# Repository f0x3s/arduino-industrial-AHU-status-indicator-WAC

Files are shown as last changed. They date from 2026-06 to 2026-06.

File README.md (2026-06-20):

# Arduino Industrial AHU Status Indicator

This project exists as a part of larger infrasctructure to support the laser cutter & digital fabrication space at the Walker Art Center. The laser cutter is vented using an inline blower fan into our paint booth's air handling system several rooms over. It is important that both the inline fan and the paint booth's air handling unit (AHU) are on during laser operation. 

It is easy to verify the status of the inline blower as it is next to the laser, but with the AHU in a separate location a feedback system is required to monitor that the start signal was successfully recieved and alert if the unit turns off for any reason.

<p align="center">
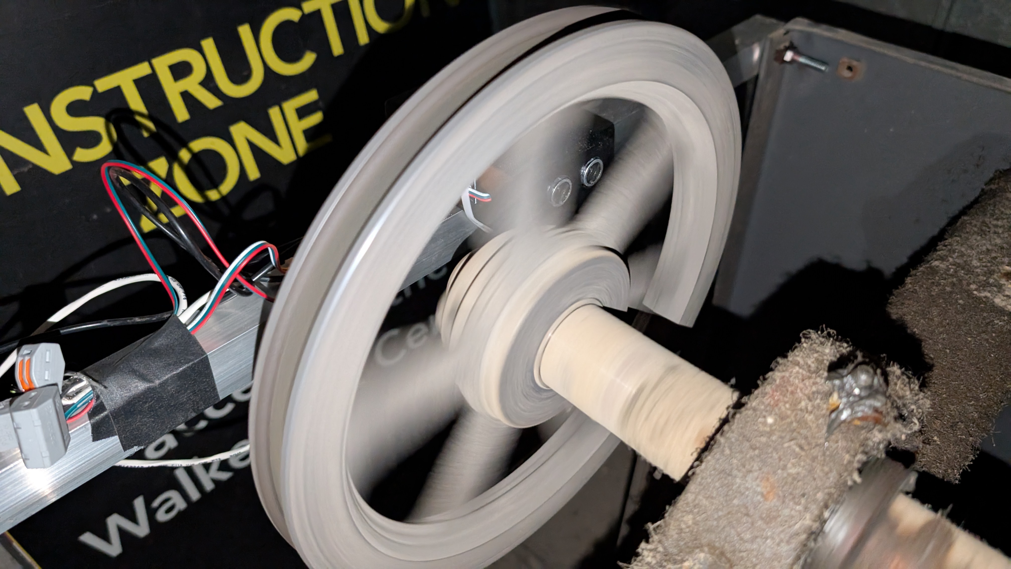
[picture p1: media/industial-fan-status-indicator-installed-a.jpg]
  
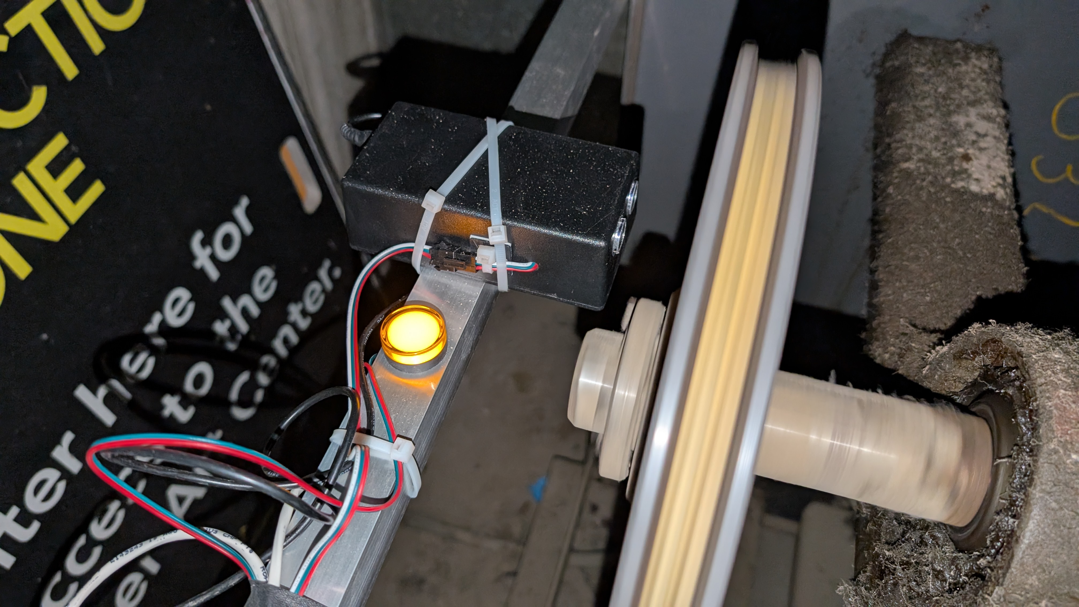
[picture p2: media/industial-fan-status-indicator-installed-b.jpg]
  
</p>

> [Return to: laser-cutter-infrastructure-controls-system-WAC](https://github.com/f0x3s/laser-cutter-infrastructure-controls-system-WAC)
## Behavior

The device uses an ultrasonic sensor to detect passing spokes on the belt and pully system driving the AHU, eliminating any possible ambiguity as to the system's operation. It does this by writing the distance output from the sensor at short intervals into a circular buffer, evaluating for the maximum and minimum distances within the buffer, and triggering a relay if the difference between them exceeds a set threshold. If the fan stops spinning, regardess of whether the pully lands with a spoke or hole in front of the sensor, the buffer will fill up with identical values, and with the threshold no longer met the relay will be deactivated. 

## Required components

* 1x Arduino Uno
* 1x HC-SR04 Ultrasonic Sensor
* 1x 5v Relay Module
* Jumper wire (as needed)
* 2x 24v Indicator lamp
* 1x Project enclosure
* 1x 9v Barrel-jack PSU.
* Wago connectors (as needed)
* Two-conductor stranded wire (as needed)

## Circuit Diagram

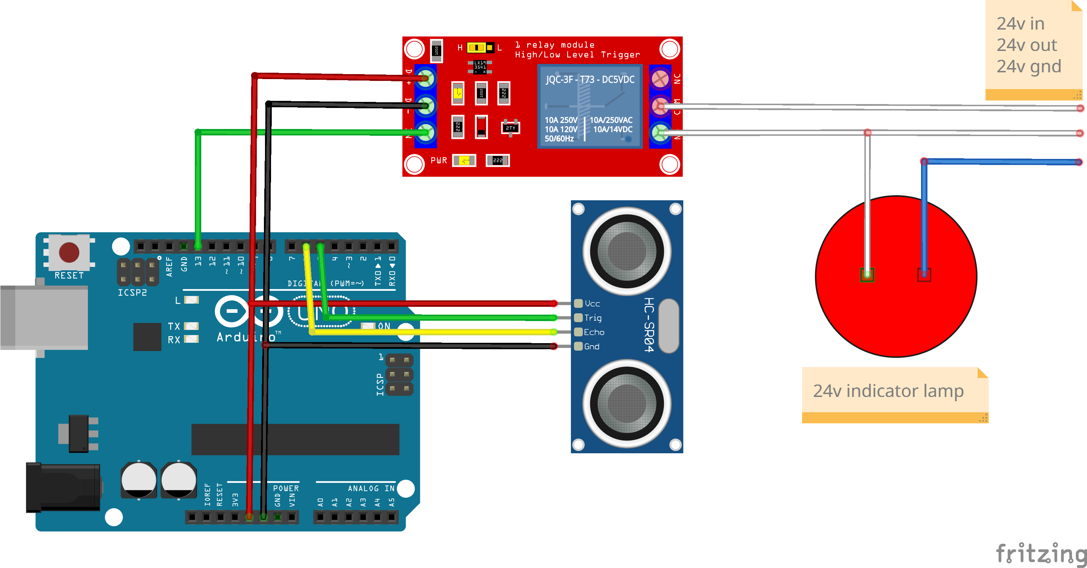
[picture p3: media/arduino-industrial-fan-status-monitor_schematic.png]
electrical schematic


Notes:
* 24v IN to the relay's COM terminal is sourced from the user AHU start signal. This signal remains on for the duration that laser is engaged. This ensures that the feedback lamp will illuminate IFF the fan is spinning && the user has sent a start signal. The lamp will not illuinate if the AHU is activated by someone in the paint booth but an activation request isn't sent from the laser cutter, minimizing confusion.
* Indicator lamp shown on schematic is to placed near the device (see main photos), for local operational verification. The second indicator lamp is placed in room with the laser cutter, receiving the samee 24v signal out from the NO relay terminal and acting as the primary status indiator for the user.
* 24v signals sent over 2-conductor speaker wire or equivalent, all other wires shown are small jumper wires.

## Debugging

sample expected serial output:
<br>
<br>
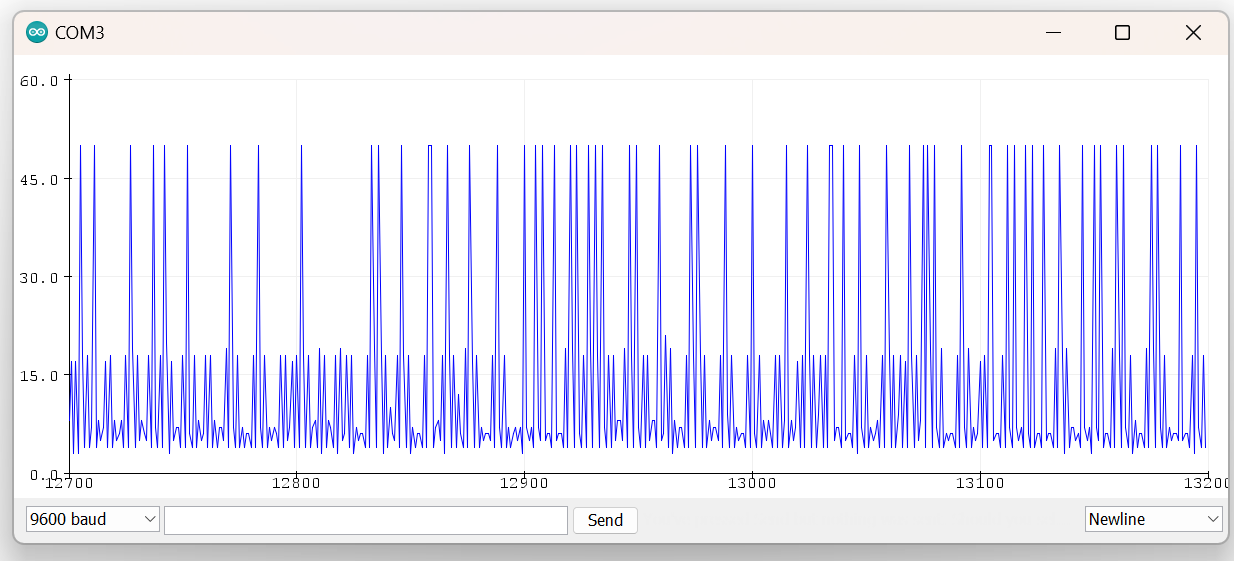
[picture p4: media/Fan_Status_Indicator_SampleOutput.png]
example serial output

<br>
<br>
If the relay is not triggering, the spoke/no spoke distance values may be identified with the serial plotter and the threshold adjusted accordingly.

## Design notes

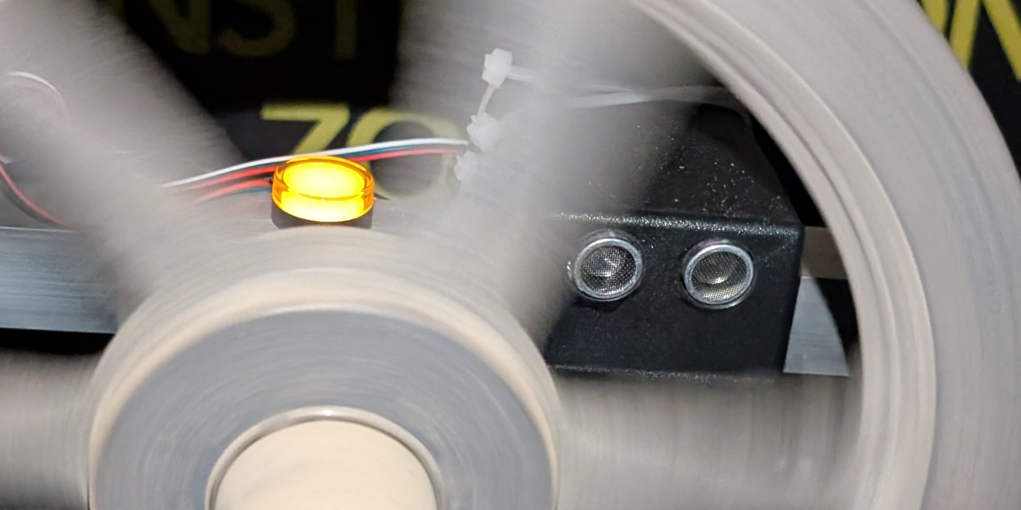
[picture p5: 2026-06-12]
media/preview-image.jpg

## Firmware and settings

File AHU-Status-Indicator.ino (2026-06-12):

/*
  Industrial Fan State Monitor

  <desc>

  see details: github link

  created 10 Jun 2026
  by foxes
  modified 11 Jun 2026
  by foxes


*/

#include <math.h>

const int trigPin = 5;
const int echoPin = 6;

const unsigned long REST_INTERVAL_US = 50000;
const unsigned long CLEAR_TIME_US = 2;
const unsigned long TRIG_TIME_US = 10;
const unsigned long ECHO_TIMEOUT_US = 30000;

const int maxDist = 50;

enum SensorState {
  RESTING,
  CLEAR_TRIGGER,
  SEND_TRIGGER,
  WAIT_FOR_ECHO_START,
  WAIT_FOR_ECHO_END
};

SensorState state = RESTING;

unsigned long stateStartMicros = 0;
unsigned long echoStartMicros = 0;
unsigned long lastReadingMicros = 0;

int distance = 0;

float thresh = 30;

const size_t BUFFER_SIZE = 50;
float buffer[BUFFER_SIZE];
size_t head = 0;
size_t count = 0;

bool newReading = false;

void setup() {
  pinMode(trigPin, OUTPUT);
  pinMode(echoPin, INPUT);

  digitalWrite(trigPin, LOW);

  for (size_t i = 0; i < BUFFER_SIZE; i++) {
    buffer[i] = 0;
  }
  
  pinMode(LED_BUILTIN, OUTPUT);
  
  Serial.begin(9600);
  
}

void loop() {
  unsigned long now = micros();

  newReading = false;

  checkSensor(now);
  
  if (newReading && count > 1 && fabs(getMax() - getMin()) > thresh) {
    digitalWrite(LED_BUILTIN, HIGH);

  } else if (newReading) {
    digitalWrite(LED_BUILTIN, LOW);

  }
}

void checkSensor(unsigned long now) {
  switch (state) {
    
    case RESTING:
      if (now - lastReadingMicros >= REST_INTERVAL_US) {
        digitalWrite(trigPin, LOW);
        stateStartMicros = now;
        state = CLEAR_TRIGGER;
      }
      break;

    case CLEAR_TRIGGER:
      if (now - stateStartMicros >= CLEAR_TIME_US) {
        digitalWrite(trigPin, HIGH);
        stateStartMicros = now;
        state = SEND_TRIGGER;
      }
      break;

    case SEND_TRIGGER:
      if (now - stateStartMicros >= TRIG_TIME_US) {
        digitalWrite(trigPin, LOW);
        stateStartMicros = now;
        state = WAIT_FOR_ECHO_START;
      }
      break;

    case WAIT_FOR_ECHO_START:
      if (digitalRead(echoPin) == HIGH) {
        echoStartMicros = now;
        state = WAIT_FOR_ECHO_END;
      }

      if (now - stateStartMicros >= ECHO_TIMEOUT_US) {
        lastReadingMicros = now;
        state = RESTING;
      }
      break;

    case WAIT_FOR_ECHO_END:
      if (digitalRead(echoPin) == LOW) {
        unsigned long duration = now - echoStartMicros;

        distance = duration * 0.034 / 2;

        if (distance > maxDist) {
          distance = maxDist;
        }

        addToBuffer(distance);
        newReading = true;

        lastReadingMicros = now;
        state = RESTING;
      }

      if (now - echoStartMicros >= ECHO_TIMEOUT_US) {
        lastReadingMicros = now;
        state = RESTING;
      }
      break;
  }
}

void addToBuffer(float value) {
  if (count < BUFFER_SIZE) {
    count++;
  }

  buffer[head] = value;
  Serial.println(value);
  head = (head + 1) % BUFFER_SIZE;
}

float getMax() {
  if (count == 0) return NAN;
  
  float maxVal = buffer[0];
  
  for (size_t i = 1; i < count; i++) {
    if (buffer[i] > maxVal) {
      maxVal = buffer[i];
    }
  }
  
  return maxVal;
}

float getMin() {
  if (count == 0) return NAN;
  
  float minVal = buffer[0];
  
  for (size_t i = 1; i < count; i++) {
    if (buffer[i] < minVal) {
      minVal = buffer[i];
    }
  }
  
  return minVal;
}

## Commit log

2026-06-11 Update Industrial-Fan-Status-Indicator.ino
    Updated description - copied formatting from Arduino example code and left that author's name in there :^)
2026-06-12 added circuit diagram image
2026-06-12 added schematic source
    [arduino-industrial-fan-status-monitor.fzz]
